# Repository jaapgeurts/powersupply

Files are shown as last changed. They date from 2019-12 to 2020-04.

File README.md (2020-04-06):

# Variable power supply

This project is my first attempt at a variable voltage power supply with current limiting.

The power supply can regulate from 0-25v and handle about 3 Amps depending on how well the series pass transistor is heatsinked.

Regulation is not very stable when current limiting kicks in. This requires further analysis.

If you've built and/or improved this project I would like to hear from you.

**Warning**

I make no guarantees towards the correctness or quality of this project.

If you decide to build this project and use this power supply, you do so at your own risk.

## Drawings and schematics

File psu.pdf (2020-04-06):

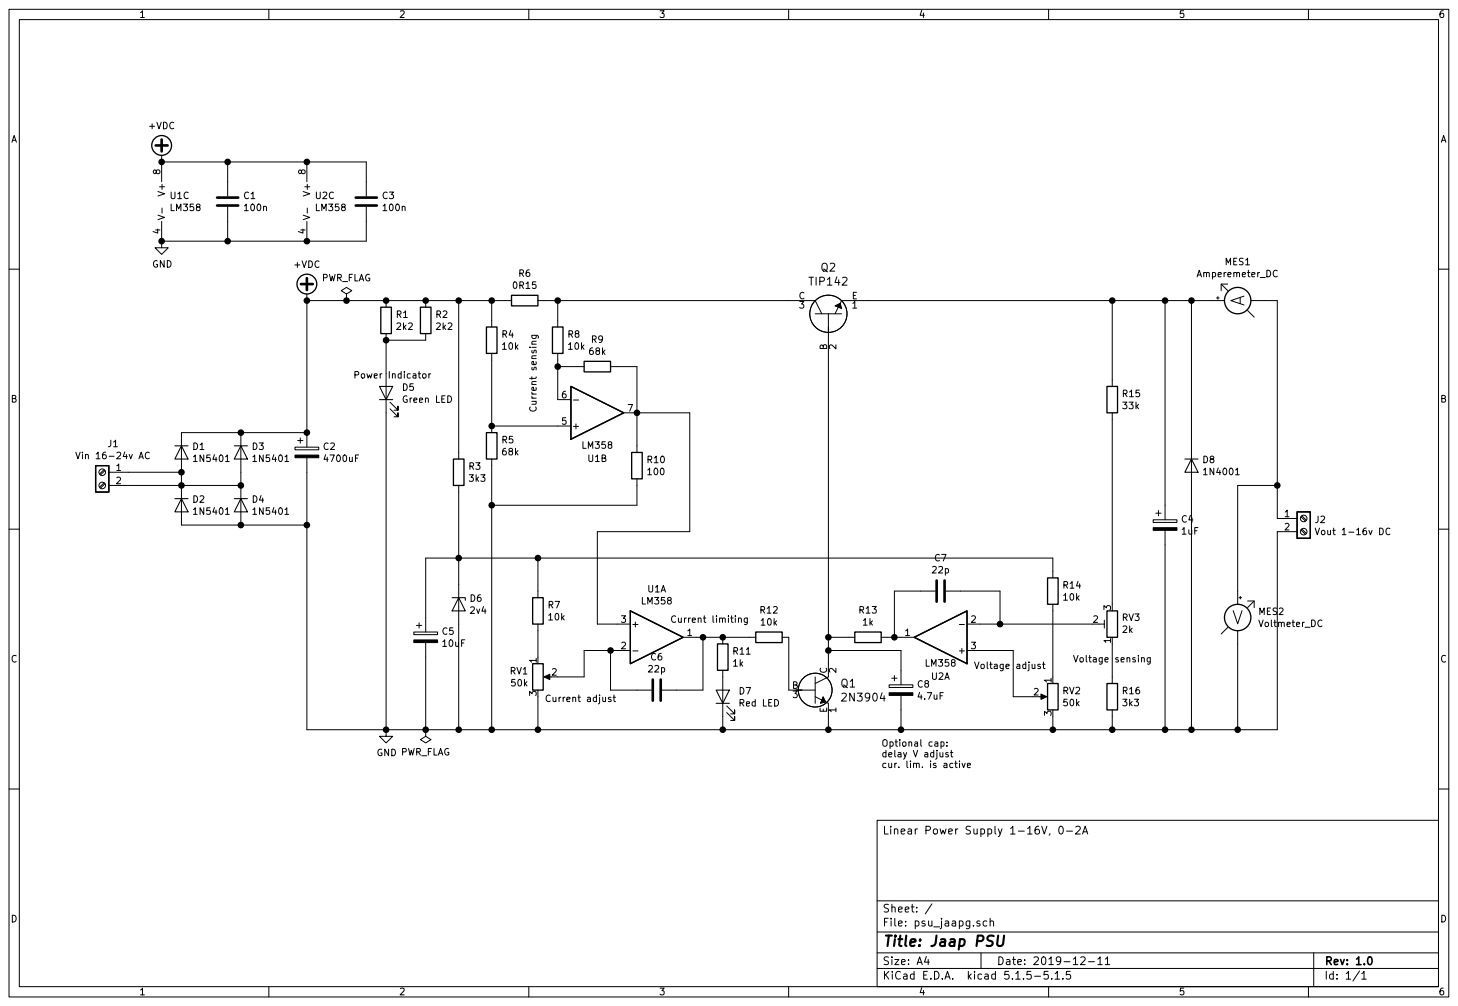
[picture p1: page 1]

File: psu_jaapg.sch Sheet: / Linear Power Supply 1-16V, 0-2A

Id: 1/1 Title: Jaap PSU

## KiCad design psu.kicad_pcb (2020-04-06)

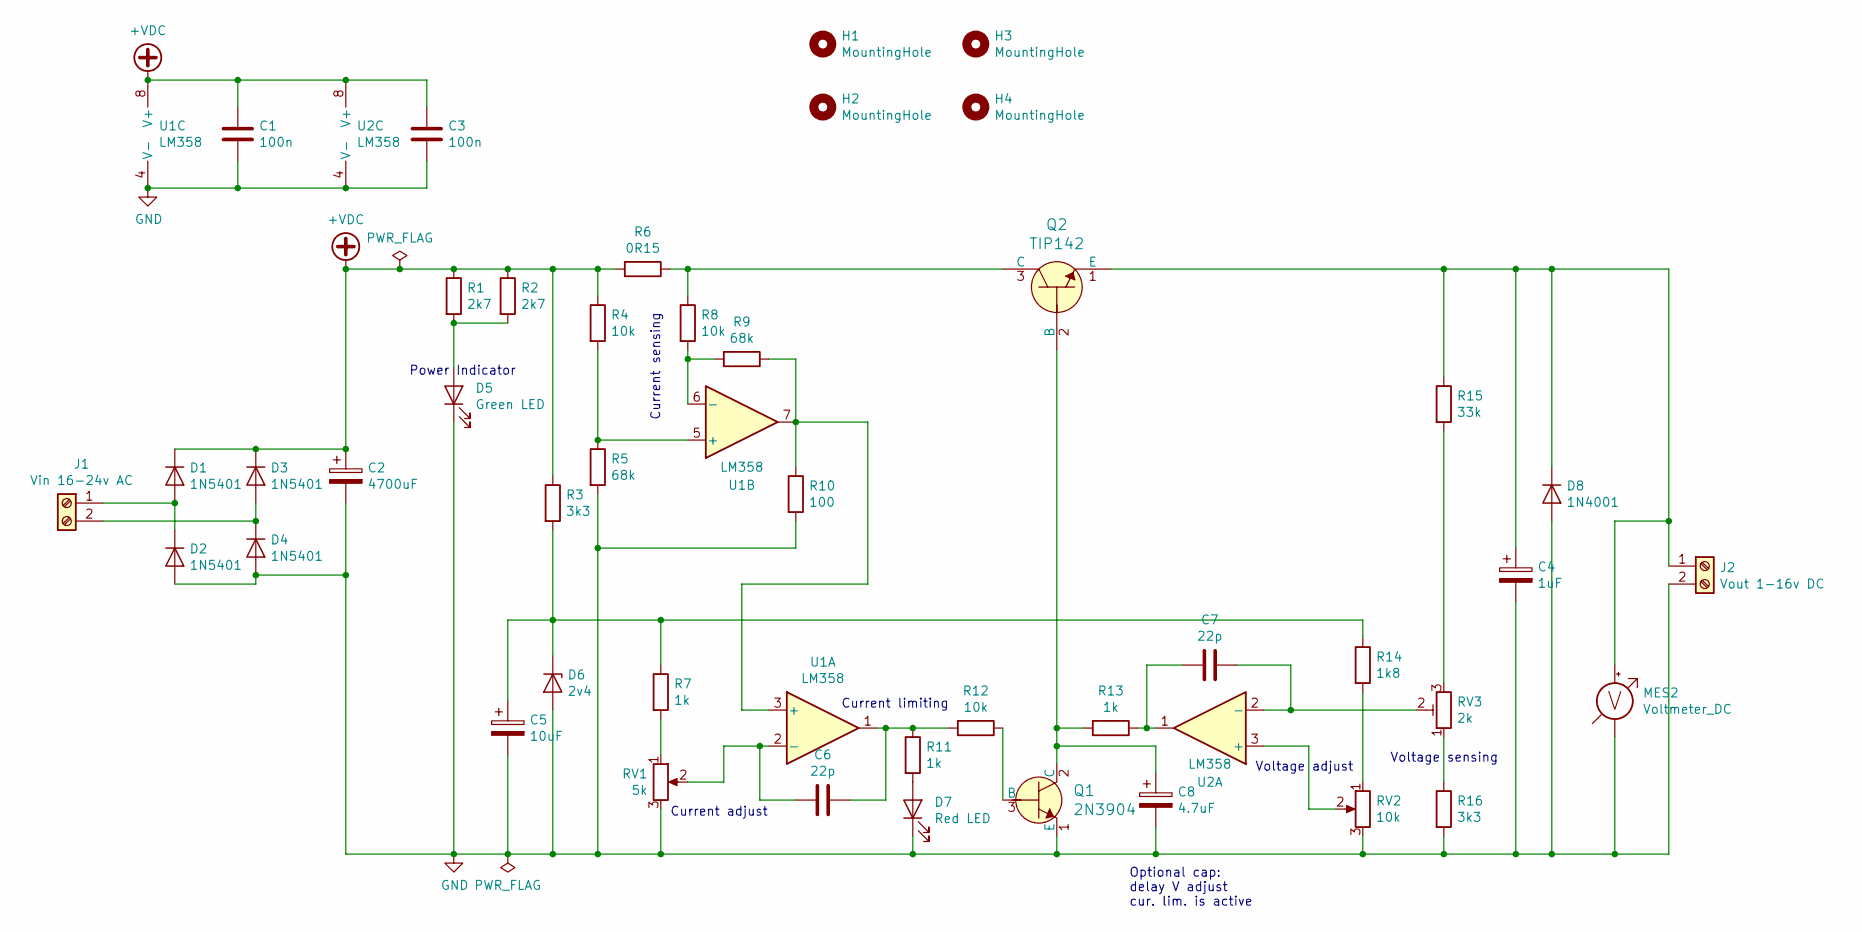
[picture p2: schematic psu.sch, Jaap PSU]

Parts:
C1, C3: 100n; C_Disc_D5.1mm_W3.2mm_P5.00mm
C2: 4700uF; CP_Radial_D16.0mm_P7.50mm
C4: 1uF; CP_Radial_D5.0mm_P2.50mm
C5: 10uF; CP_Radial_D5.0mm_P2.50mm
C6, C7: 22p; C_Disc_D5.1mm_W3.2mm_P5.00mm
C8: 4.7uF; CP_Radial_D5.0mm_P2.50mm
D1, D2, D3, D4: 1N5401; D_DO-201AD_P15.24mm_Horizontal
D5: Green LED; PinHeader_1x02_P2.54mm_Vertical
D6: 2v4; D_DO-35_SOD27_P10.16mm_Horizontal
D7: Red LED; PinHeader_1x02_P2.54mm_Vertical
D8: 1N4001; D_DO-41_SOD81_P10.16mm_Horizontal
H1, H2, H3, H4: MountingHole; MountingHole_4.3mm_M4
J1: Vin 16-24v AC; TerminalBlock_Altech_AK300-2_P5.00mm
J2: Vout 1-16v DC; TerminalBlock_Altech_AK300-2_P5.00mm
MES2: Voltmeter_DC; PinHeader_1x02_P2.54mm_Vertical
Q1: 2N3904; TO-92_HandSolder_LongPads; MPN 2N3904; Digi-Key_PN 2N3904CS-ND
Q2: TIP142; PinHeader_1x03_P2.54mm_Vertical; MPN TIP142; Digi-Key_PN 497-2541-5-ND
R1, R2: 2k7; R_Axial_DIN0207_L6.3mm_D2.5mm_P10.16mm_Horizontal
R3, R16: 3k3; R_Axial_DIN0207_L6.3mm_D2.5mm_P10.16mm_Horizontal
R4, R8, R12: 10k; R_Axial_DIN0207_L6.3mm_D2.5mm_P10.16mm_Horizontal
R5, R9: 68k; R_Axial_DIN0207_L6.3mm_D2.5mm_P10.16mm_Horizontal
R6: 0R15; R_Axial_DIN0617_L17.0mm_D6.0mm_P20.32mm_Horizontal
R7, R11, R13: 1k; R_Axial_DIN0207_L6.3mm_D2.5mm_P10.16mm_Horizontal
R10: 100; R_Axial_DIN0207_L6.3mm_D2.5mm_P10.16mm_Horizontal
R14: 1k8; R_Axial_DIN0207_L6.3mm_D2.5mm_P10.16mm_Horizontal
R15: 33k; R_Axial_DIN0207_L6.3mm_D2.5mm_P10.16mm_Horizontal
RV1: 5k; PinHeader_1x03_P2.54mm_Vertical
RV2: 10k; PinHeader_1x03_P2.54mm_Vertical
RV3: 2k; Potentiometer_Runtron_RM-063_Horizontal
U1, U2: LM358; DIP-8_W7.62mm_LongPads

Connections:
+VDC: C1.1, C2.1, C3.1, D1.1 (K), D3.1 (K), R1.1, R2.1, R3.1, R4.1, R6.2, U1.8 (V+), U2.8 (V+)
GND: C1.2, C2.2, C3.2, C4.2, C5.2, C8.2, D2.2 (A), D4.2 (A), D5.1 (K), D6.2 (A), D7.1 (K), D8.2 (A), J2.2, MES2.1 (-), Q1.1 (E), R5.2, R10.2, R16.2, RV1.3, RV2.3, U1.4 (V-), U2.4 (V-)
unnamed: C4.1, D8.1 (K), J2.1, MES2.2 (+), Q2.1 (E), R15.1
unnamed: C5.1, D6.1 (K), R3.2, R7.1, R14.1
unnamed: C6.1, R11.1, R12.2, U1.1
unnamed: C6.2, RV1.2, U1.2 (-)
unnamed: C7.1, RV3.2, U2.2 (-)
unnamed: C7.2, R13.1, U2.1
unnamed: C8.1, Q1.2 (C), Q2.2 (B), R13.2
unnamed: D1.2 (A), D2.1 (K), J1.1
unnamed: D3.2 (A), D4.1 (K), J1.2
unnamed: D5.2 (A), R1.2, R2.2
unnamed: D7.2 (A), R11.2
unnamed: Q1.3 (B), R12.1
unnamed: Q2.3 (C), R6.1, R8.1
unnamed: R4.2, R5.1, U1.5 (+)
unnamed: R7.2, RV1.1
unnamed: R8.2, R9.2, U1.6 (-)
unnamed: R9.1, R10.1, U1.3 (+), U1.7
unnamed: R14.2, RV2.1
unnamed: R15.2, RV3.3
unnamed: R16.1, RV3.1
unnamed: RV2.2, U2.3 (+)

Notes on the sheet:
Optional cap: delay V adjust cur. lim. is active
Current adjust
Voltage adjust
Voltage sensing
Current sensing
Current limiting
Power Indicator

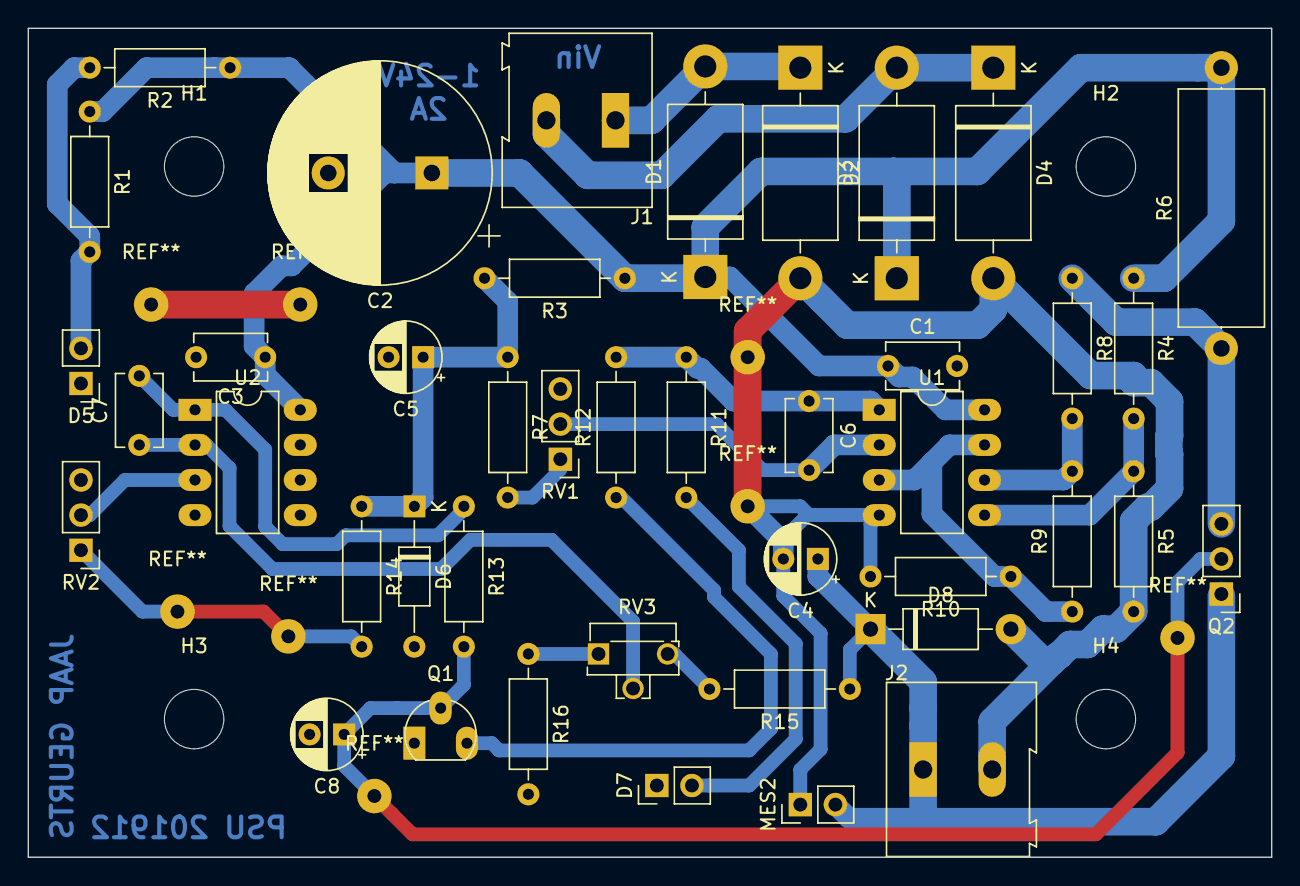
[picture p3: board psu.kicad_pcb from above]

Board: 2 copper layers, 90.0 x 60.0 mm, 46 parts (0 on the bottom side), 23 nets.

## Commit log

2019-12-11 Circuit Schematic complete
    [psu_jaapg.kicad_pcb, psu_jaapg.sch]
2019-12-16 First etched version
    [psu_jaapg.kicad_pcb, psu_jaapg.sch]
